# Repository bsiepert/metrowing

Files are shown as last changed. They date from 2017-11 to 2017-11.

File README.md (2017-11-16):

# metrowing
A an adapter to use Adafruit featherwings with Adafruit Metros or Arduino Unos

[BOM on Octopart](https://octopart.com/bom-tool/s72yPqrf)

mkii fixes/updates:
* Adds a SPI header so that we can pick up the SPI/ICSP header on the Metro and route MOSI/MISO/SCK to the appropriate FeatherWing pins. A female ICSP header should be mounted *underneath* the featherwing so that it can plug into the male ICSP header on the Metro. This will allow for use of the LoRa feathers and others that need SPI
* Routes the Metro's +5v to the USB power rails on the feather for Wings that need more juice like the NeoPixel Featherwing
* Adjusts header locations for better clearance
* Fixes pin labels 
* Changes Reset button
* Added 15 pieces of flair

As of 11/15/17 this version is untested

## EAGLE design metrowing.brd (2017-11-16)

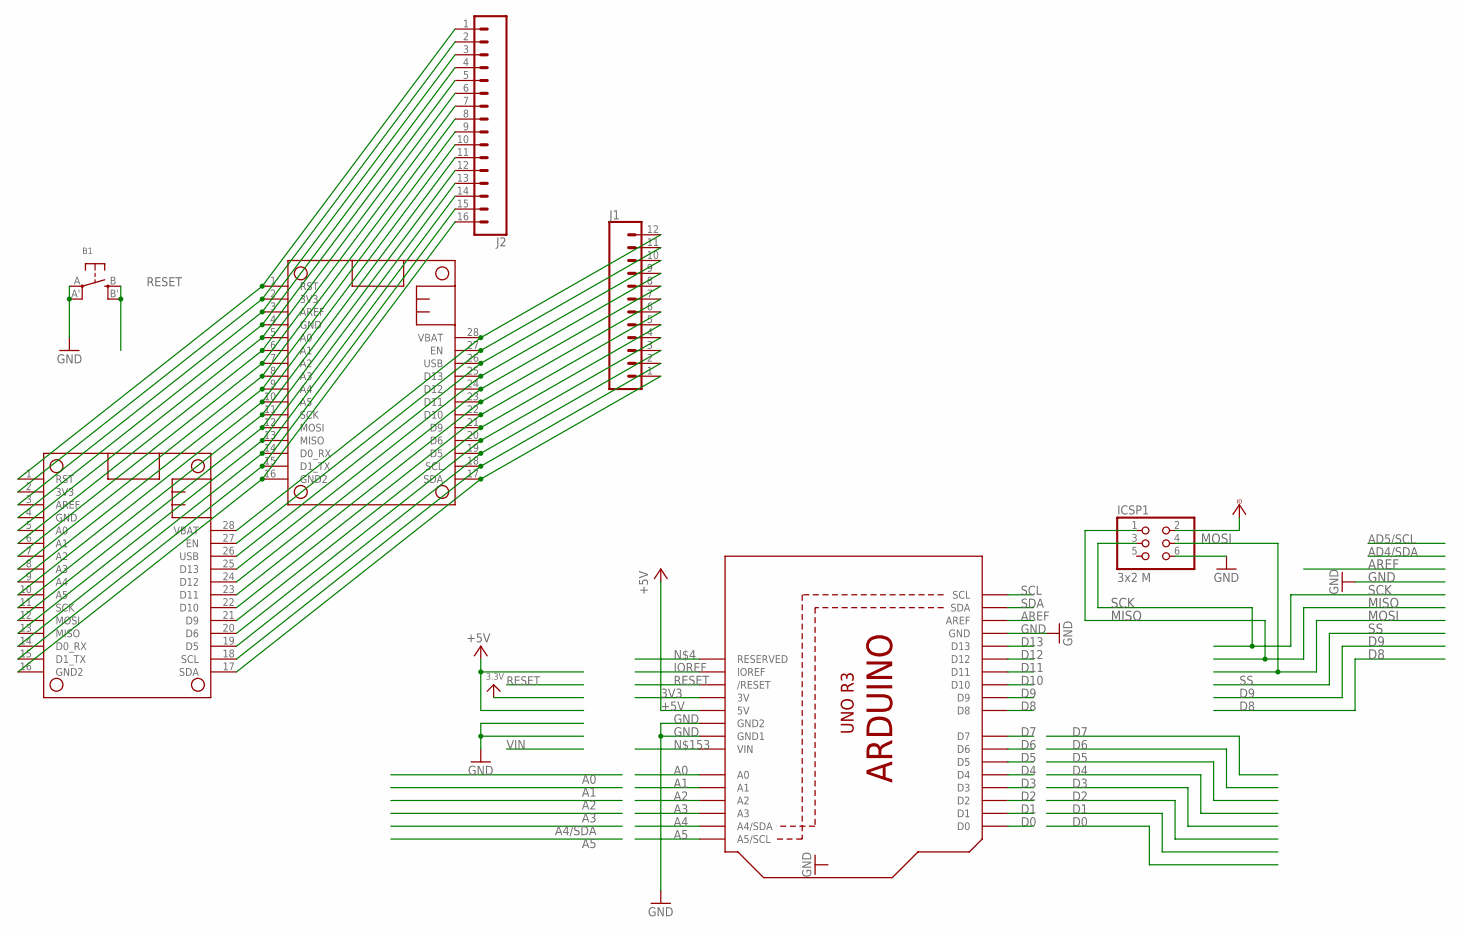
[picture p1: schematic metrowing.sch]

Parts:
B1: SWITCH_TACT_SMT; EVQ-Q2
ICSP1: 3x2 M; 2X03_ROUND_70MIL
J1: CONN_12; 1X12
J2: CONN_16; 1X16
MS1, MS2: FEATHERWING_PINS
U1: ARDUINOR3-DIMENSION; ARDUINOR3

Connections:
3V3: J2.2, MS1.2 (3V3), MS2.2 (3V3), U1.3V
+5V: J1.10, MS1.26 (USB), MS2.26 (USB), U1.5V
A0: J2.5, MS1.5 (A0), MS2.5 (A0), U1.A0
A1: J2.6, MS1.6 (A1), MS2.6 (A1), U1.A1
A2: J2.7, MS1.7 (A2), MS2.7 (A2), U1.A2
A3: J2.8, MS1.8 (A3), MS2.8 (A3), U1.A3
A4: J2.9, MS1.9 (A4), MS2.9 (A4), U1.A4 (A4/SDA)
A5: J2.10, MS1.10 (A5), MS2.10 (A5), U1.A5 (A5/SCL)
AREF: J2.3, MS1.3 (AREF), MS2.3 (AREF), U1.AREF
D0: J2.14, MS1.14 (D0_RX), MS2.14 (D0_RX), U1.D0
D1: J2.15, MS1.15 (D1_TX), MS2.15 (D1_TX), U1.D1
D2: U1.D2
D3: U1.D3
D4: U1.D4
D5: J1.3, MS1.19 (D5), MS2.19 (D5), U1.D5
D6: J1.4, MS1.20 (D6), MS2.20 (D6), U1.D6
D7: U1.D7
D8: U1.D8
D9: J1.5, MS1.21 (D9), MS2.21 (D9), U1.D9
D10: J1.6, MS1.22 (D10), MS2.22 (D10), U1.D10
D11: J1.7, MS1.23 (D11), MS2.23 (D11), U1.D11
D12: J1.8, MS1.24 (D12), MS2.24 (D12), U1.D12
D13: J1.9, MS1.25 (D13), MS2.25 (D13), U1.D13
ENABLE: J1.11, MS1.27 (EN), MS2.27 (EN)
GND: B1.A, B1.A' (P1), ICSP1.6, J2.4, J2.16, MS1.4 (GND), MS1.16 (GND2), MS2.4 (GND), MS2.16 (GND2), U1.GND, U1.GND1, U1.GND2
IOREF: U1.IOREF
MISO: ICSP1.1, J2.13, MS1.13 (MISO), MS2.13 (MISO)
MOSI: ICSP1.4, J2.12, MS1.12 (MOSI), MS2.12 (MOSI)
RESET: B1.B (S), B1.B' (S1), J2.1, MS1.1 (RST), MS2.1 (RST), U1.RESET (/RESET)
SCK: ICSP1.3, J2.11, MS1.11 (SCK), MS2.11 (SCK)
SCL: J1.2, MS1.18 (SCL), MS2.18 (SCL), U1.SCL
SDA: J1.1, MS1.17 (SDA), MS2.17 (SDA), U1.SDA
VBAT: J1.12, MS1.28 (VBAT), MS2.28 (VBAT)
VCCIO: ICSP1.2

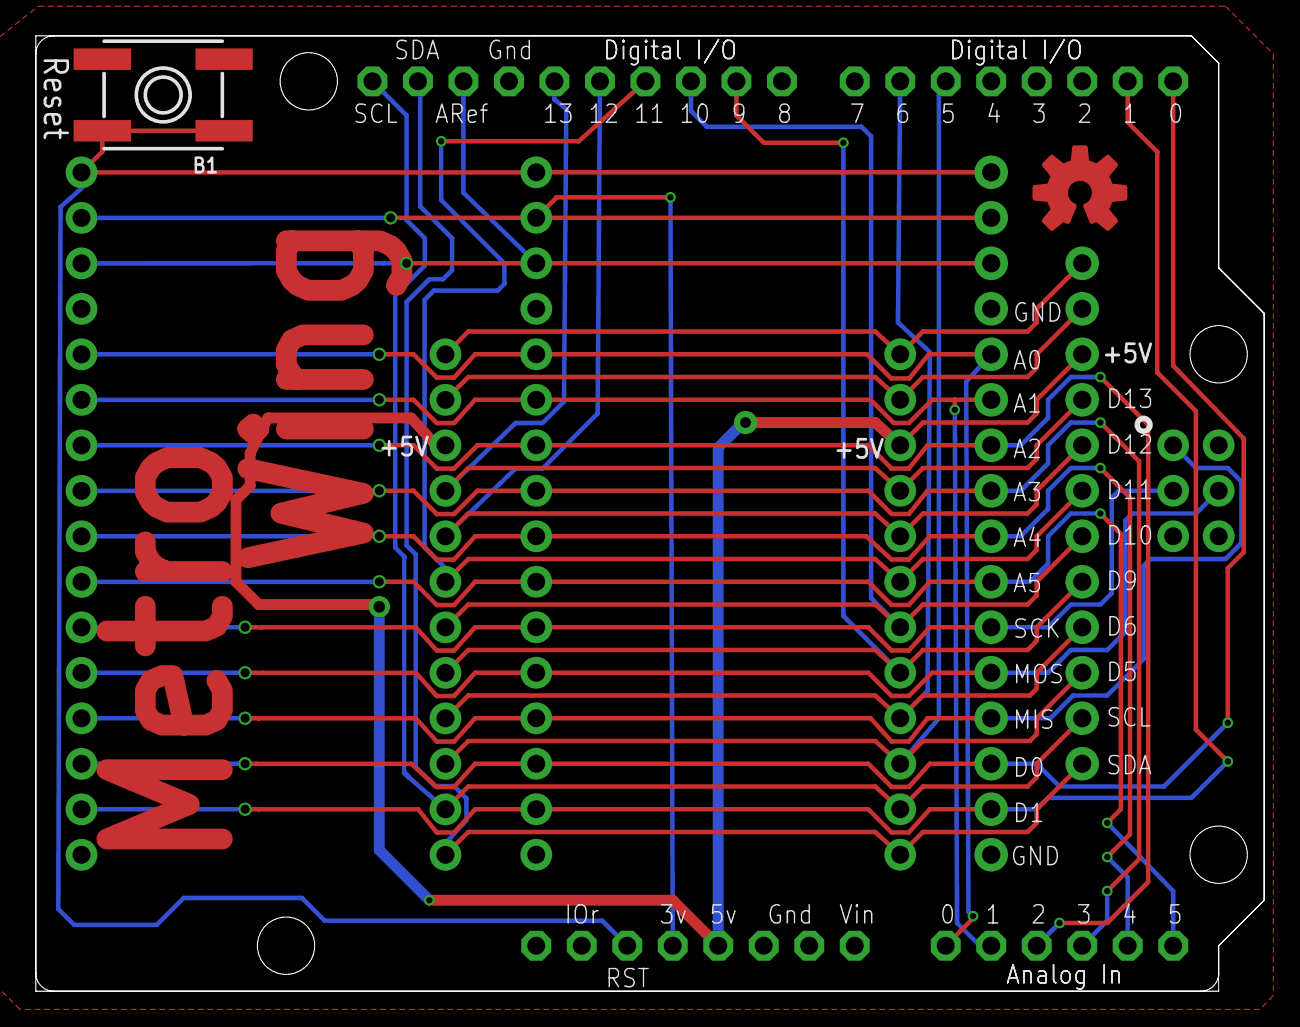
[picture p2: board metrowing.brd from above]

Board: 2 copper layers, 68.6 x 53.3 mm, 8 parts (0 on the bottom side), 27 nets.

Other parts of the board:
U$1: OSHWLOGO_TOP_0.2

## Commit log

2017-10-20 Initial routed version
    [metrowing.brd, metrowing.sch]
2017-10-20 correct (mkii) version
    [metrowing.brd, metrowing.sch]
2017-10-20 fixed clearance drc
    [metrowing.brd]
2017-10-27 Broken SPI Notificaion
2017-11-16 updated and fixed mkii: Now with more SPI
    [metrowing.brd, metrowing.sch]

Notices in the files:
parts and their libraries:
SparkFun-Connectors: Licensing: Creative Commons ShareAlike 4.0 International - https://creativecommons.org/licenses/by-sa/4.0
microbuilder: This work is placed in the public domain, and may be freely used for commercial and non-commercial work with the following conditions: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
